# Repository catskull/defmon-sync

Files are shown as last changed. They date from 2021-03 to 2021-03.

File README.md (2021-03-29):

# defMon Sync Adapter 
This is an adapter for the Commodore 64 computer. It is used to synchronize a tracker called [defMon](https://www.vandervecken.com/defmon/doku.php?id=download:download) with other music equipment.

It connects to the user port and outputs the following signals:
- LSDJ sync signal.
- nanoloop sync signal.
- midi clock.
- din sync.
- clock signal with adjustable resolution from 24ppqn to 2ppqn for Korg Volcas, TE Pocket Operators, Arturia Microbrute, MI Anushri etc.

It can only work as master.

It should also work with Prophet64.

# Purpose
ScannerBoy originally created and sold these devices but has since stopped. Due to demand, this is an effort to make hardware. To aid in this, the code is being ported to Arduino/MiniCore.

## Building/Flashing
- Install Arduino IDE (1.8.13)
- [Install MiniCore](https://github.com/MCUdude/MiniCore)
- Download/clone this repo and open the defmon-sync.ino file
- Select ATmega8 board from the boards dropdown
- For clock, selecte "External 20 MHz"
- Leave other options the defaults
- Connect a USB-serial adapter to the onboard FTDI header
- Select the serial port in Arduino menu, and hit upload!

# Credits
Original developer: Krzysztof Iwanowski

Additional PCB work by Orgia Mode

Arduino port by catskull

# License
The firmware, PCB layouts and schematics are released under a Creative Commons cc-by-sa 3.0 license.

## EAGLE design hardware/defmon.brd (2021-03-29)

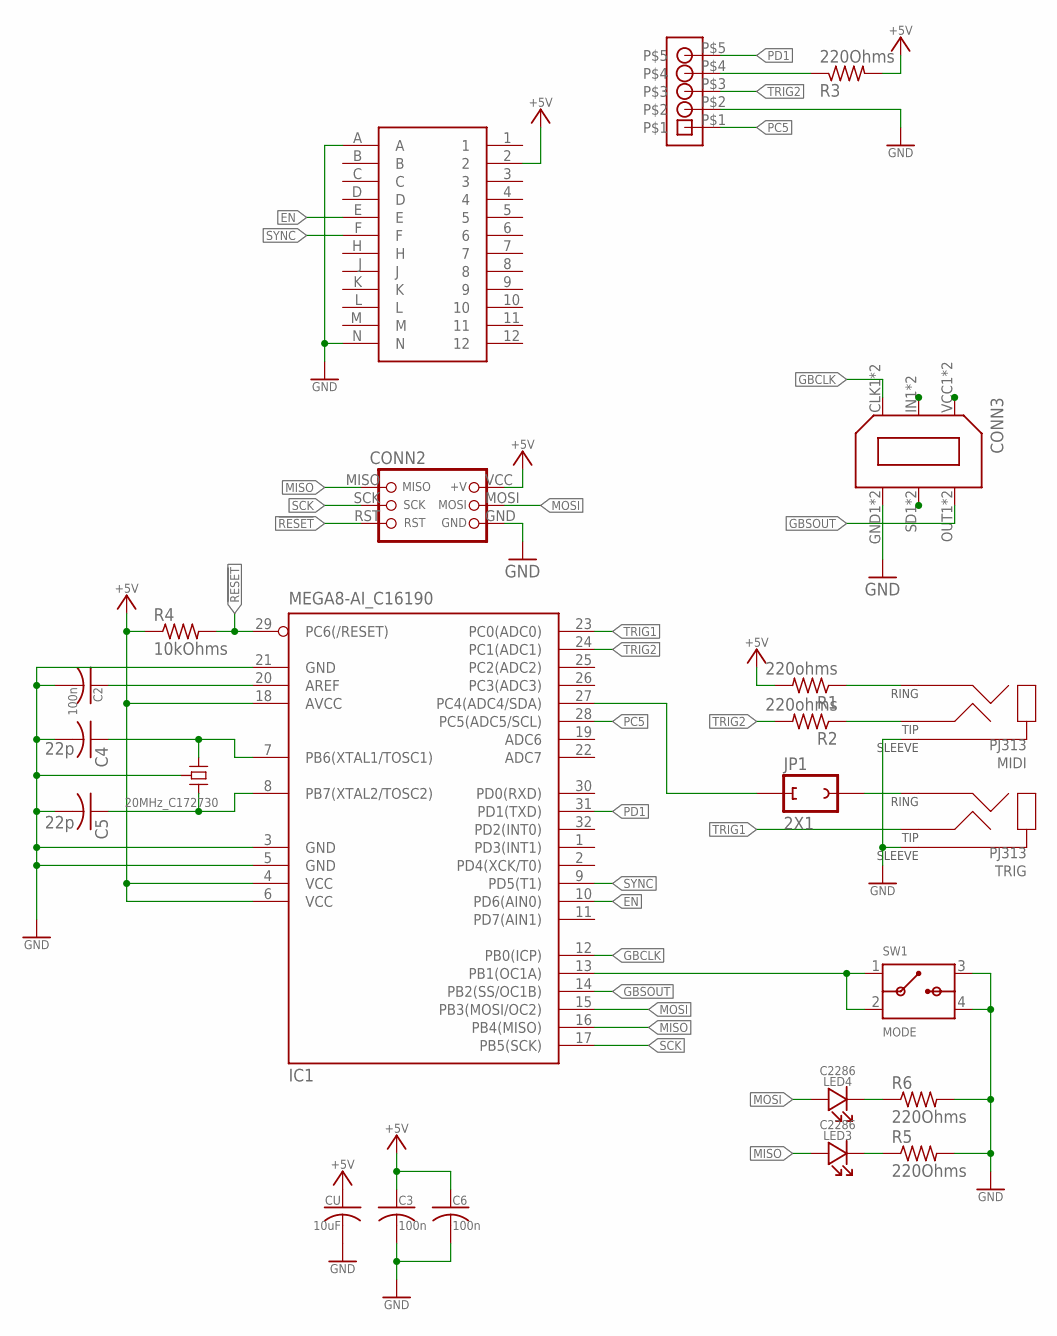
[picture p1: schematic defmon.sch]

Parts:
C2, C3, C6: 100n; C0603K
C4, C5: 22p; C0603K
CONN2: DNP; ICSP_SMD_PROBE
CONN3: LINK_PORTFINAL; DUAL_BAORD_LINK_FINAL
CU: 10uF; C0603K
DIN: 1X5
IC1: MEGA8-AI_C16190; TQFP32-08
JP1: 2X1
LED3, LED4: C2286; 0603K
MIDI: PJ313; PJ313D
Q1: 20MHz_C172730; SX3225
R1, R2: 220ohms; R0603
R3, R5, R6: 220Ohms; R0603
R4: 10kOhms; R0603
SW1: MODE; TS5215A
TRIG: PJ313; PJ313D
U$2: CONNECTOR_C64UJ; C64_USERPORT

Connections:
!RESET: CONN2.RST, IC1.29 (PC6(/RESET)), R4.2
+5V: C3.1, C6.1, CONN2.VCC (+V), CU.1, IC1.4 (VCC), IC1.6 (VCC), IC1.18 (AVCC), R1.2, R3.2, R4.1, U$2.2
AREF: C2.1, IC1.20 (AREF)
EN: IC1.10 (PD6(AIN0)), U$2.E
GBCLK: CONN3.CLK1 (CLK), CONN3.CLK2 (CLK), IC1.12 (PB0(ICP))
GBSOUT: CONN3.OUT1 (OUT), CONN3.OUT2 (OUT), IC1.14 (PB2(SS/OC1B))
GND: C2.2, C3.2, C4.2, C5.2, C6.2, CONN2.GND, CONN3.GND1 (GND), CONN3.GND2 (GND), CU.2, DIN.P$2, IC1.3 (GND), IC1.5 (GND), IC1.21 (GND), MIDI.2, MIDI.22 (2), Q1.2 (GND), Q1.4 (GND), R5.2, R6.2, SW1.3 (B1), SW1.4 (B2), TRIG.2, TRIG.22 (2), U$2.A, U$2.N
MISO: CONN2.MISO, IC1.16 (PB4(MISO)), LED3.A
MOSI: CONN2.MOSI, IC1.15 (PB3(MOSI/OC2)), LED4.A
unnamed: CONN3.VCC1 (+5V), CONN3.VCC2 (+5V)
unnamed: CONN3.SD1 (SD), CONN3.SD2 (SD)
unnamed: DIN.P$4, R3.1
unnamed: LED3.C, R5.1
unnamed: CONN3.IN1 (IN), CONN3.IN2 (IN)
unnamed: MIDI.4, MIDI.44 (4), R2.1
unnamed: LED4.C, R6.1
unnamed: C4.1, IC1.7 (PB6(XTAL1/TOSC1)), Q1.3 (X1)
unnamed: JP1.P$2 (2), TRIG.3
unnamed: IC1.27 (PC4(ADC4/SDA)), JP1.P$1 (1)
unnamed: C5.1, IC1.8 (PB7(XTAL2/TOSC2)), Q1.1 (X2)
unnamed: MIDI.3, R1.1
unnamed: IC1.13 (PB1(OC1A)), SW1.1 (A1), SW1.2 (A2)
PC5: DIN.P$1, IC1.28 (PC5(ADC5/SCL))
PD1: DIN.P$5, IC1.31 (PD1(TXD))
SCK: CONN2.SCK, IC1.17 (PB5(SCK))
SYNC: IC1.9 (PD5(T1)), U$2.F
TRIG1: IC1.23 (PC0(ADC0)), TRIG.4, TRIG.44 (4)
TRIG2: DIN.P$3, IC1.24 (PC1(ADC1)), R2.2

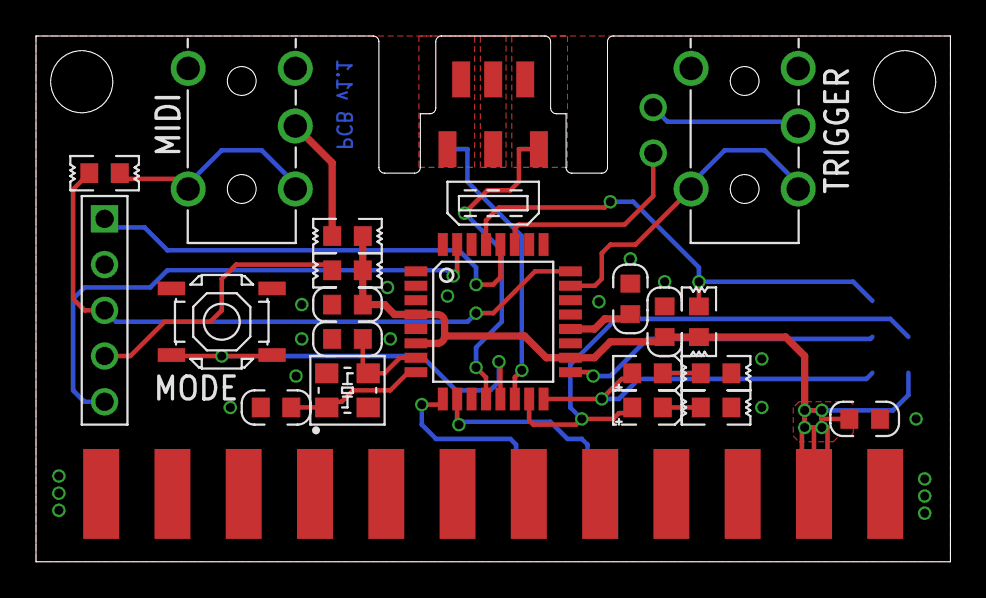
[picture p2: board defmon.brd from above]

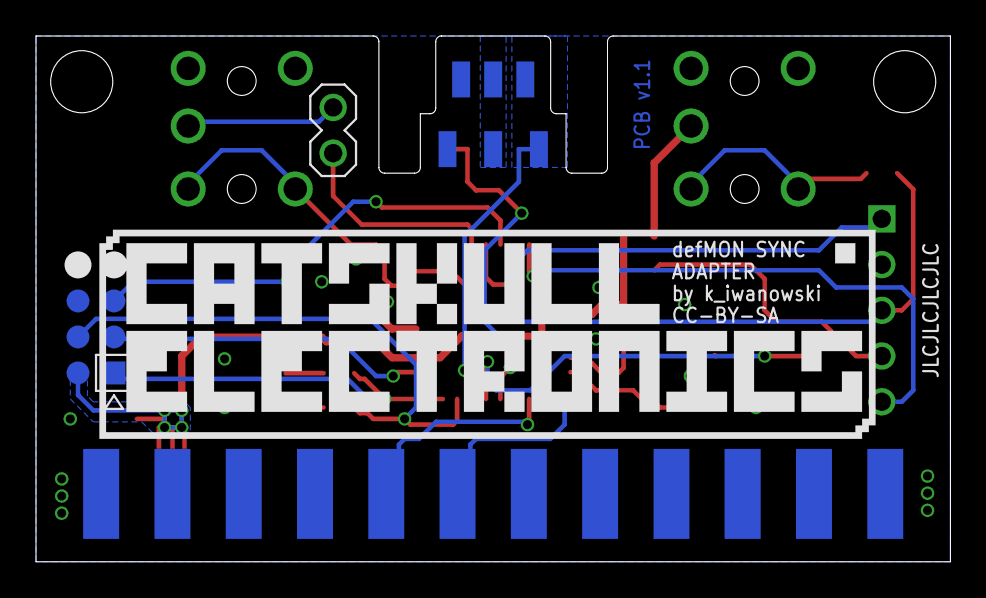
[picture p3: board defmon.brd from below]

Board: 2 copper layers, 50.8 x 29.2 mm, 28 parts (4 on the bottom side), 28 nets.

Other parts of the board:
U$1: JLCJLCJLCJLC
U$3, U$8: MOUNT4-40
U$9: CATSKULL_PIXEL_MD

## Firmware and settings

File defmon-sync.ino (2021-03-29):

//#define F_CPU 20000000L // set by arduino ide
//
//#define USART_BAUDRATE 31250 // set by Serial.begin
//#define BAUD_PRESCALE (((F_CPU / (USART_BAUDRATE * 16UL))) - 1)

//#include <avr/io.h>
//#include <avr/eeprom.h>
//#include <util/delay.h>
//#include <stdbool.h>

int LED_pin = 3, button_pin = 1, blink_counter = 0, i, div1 = 0, divtab[4] = {1,3,6,12}, counter3;
long hold_counter = 0, blink_counter2 = 0, div2;
bool gb_mode = true, sync, state = true, button_state = true, button, nano = true, midi_state = true, div_state = false, button_state2, start = true;

void setup() {
  DDRB |= _BV(3)|_BV(4)|_BV(0)|_BV(2); // led pins as outputs; gb pins as outputs (0 - lsdj, 2 - nl)
  DDRB &= ~_BV(button_pin); // button pin as input
  DDRC |= _BV(0)|_BV(1)|_BV(5); // sync24out pin as output (0,1 - sync, 5 - en)
  DDRD &= ~(_BV(5)|_BV(6)); // sync24in pins as inputs (5 - sync, 6 - en)
  PORTB |= _BV(button_pin); // internal pullup on the button input
  PORTB |= _BV(LED_pin); //led on

//  UCSR0B = (1 << TXEN0);
  Serial.begin(31250);
//  UCSR0C = (1 << UCSZ00) | (1 << UCSZ01);
//  UBRR0H = (BAUD_PRESCALE >> 8);
//  UBRR0L = BAUD_PRESCALE;
}

void loop () {
  if (start) {
    while (!eeprom_is_ready()); 
    counter3 = eeprom_read_byte(0);
    if (counter3 != 1 && counter3 != 3 && counter3 != 6 && counter3 != 12) counter3 = 1;
    div2 = counter3;
    start = false;
    }
  button = PINB & _BV(button_pin); 
  if (!button && button_state) { 
    gb_mode = !gb_mode;
    button_state = false;
    button_state2 = true;
    if (LED_pin == 3) {
      PORTB &= ~_BV(LED_pin);
      LED_pin = 4;
      PORTB |= _BV(LED_pin);
              }
    else {
      PORTB &= ~_BV(LED_pin);
      LED_pin = 3;
      PORTB |= _BV(LED_pin);
      }
    _delay_ms(10);
    }
  if (button && !button_state) {
    button_state = true;
    hold_counter = 0;
    _delay_ms(10);
    }
  if (!button_state && button_state2) {
    hold_counter++;
    if (hold_counter > 500000) {
      div_state = true;
      hold_counter = 0;
      button_state2 = false;
      }
    while(div_state) {
      blink_counter2++;
      if (blink_counter2 > div2 * 8000) {
          blink_counter2 = 0;
          if (LED_pin == 3) {
            PORTB &= ~_BV(LED_pin);
            LED_pin = 4;
            PORTB |= _BV(LED_pin);
            }
          else {
            PORTB &= ~_BV(LED_pin);
            LED_pin = 3;
            PORTB |= _BV(LED_pin);
            }
          }
      button = PINB & _BV(button_pin); 
      if (!button && button_state) {
        button_state = false;
        div1++;
        if(div1 > 3) div1 = 0;
        div2 = divtab[div1];
        counter3 = div2;
        button_state2 = true;
        _delay_ms(10);
        }
      if (button && !button_state) {
        button_state = true;
        hold_counter = 0;
        _delay_ms(10);
        }
      if (!button_state && button_state2) {
        hold_counter++;
        if (hold_counter > 500000) {
          while (!eeprom_is_ready());
          eeprom_update_byte(0, counter3);
          div_state = false;
          hold_counter = 0;
          button_state2 = false;
          }
        } 
        
      }
    }
    

  if (PIND & _BV(6)) {
    if (midi_state) {
//      while (!(UCSR0A & (1<<UDRE0))); // Do nothing until UDR is ready for more data to be written to it
//      UDR0 = 0xFA; // Send out the byte value in the variable "ByteToSend"
      Serial.write(0xFA);
      PORTC |= _BV(5); // sync24 en out on
      midi_state = false;
      }
    sync = PIND & _BV(5);
    if (sync && state) {
      if (gb_mode) {
        PORTB &= ~_BV(2);
        for(i = 0; i < 8; i ++) {
          PORTB &= ~_BV(0);
          _delay_us(60);
          PORTB |= _BV(0);
          }
        }
      else {
        if (nano) PORTB |= _BV(2);
        else PORTB &= ~_BV(2);
        nano = !nano;
        }

//      while (!(UCSR0A & (1<<UDRE0))); // Do nothing until UDR is ready for more data to be written to it
//      UDR0 = 0xF8; // Send out the byte value in the variable "ByteToSend"
      Serial.write(0xF8);
        
      if (counter3 == div2) {
        PORTC |= _BV(0); // sync24 sync out high
        counter3 = 0;
        }
        counter3++;
      PORTC |= _BV(1); // sync24 sync out high
      _delay_ms(5);
      PORTC &= ~_BV(0); // sync24 sync out low
      PORTC &= ~_BV(1); // sync24 sync out low
  
      state = false;
      blink_counter++;
      if (blink_counter == 6) {
        PORTB |= _BV(LED_pin);
        blink_counter = 0;
        }
        else PORTB &= ~_BV(LED_pin);
      }
    if (!sync && !state) state = true;
    }
  else {
    if (!midi_state) {
//      while (!(UCSR0A & (1<<UDRE0))); // Do nothing until UDR is ready for more data to be written to it
//      UDR0 = 0xFC; // Send out the byte value in the variable "ByteToSend"
      Serial.write(0xFC);
      blink_counter = 0;
      PORTB &= ~_BV(2);
      PORTB |= _BV(LED_pin);
      nano = true;
      state = true;
      PORTC &= ~_BV(5); // sync en out off
      midi_state = true;
      counter3 = div2;
      }
    }
  }

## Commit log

2021-03-29 Move hardware to a folder
    [defmon.brd, defmon.sch]
2021-03-29 Initial port of code to Arduino
2021-03-29 Update cad files
    [defmon.brd, defmon.sch]

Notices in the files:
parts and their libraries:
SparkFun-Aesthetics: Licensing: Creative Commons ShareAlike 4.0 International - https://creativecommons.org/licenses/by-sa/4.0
